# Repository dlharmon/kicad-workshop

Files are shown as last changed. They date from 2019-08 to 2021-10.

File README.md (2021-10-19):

# kicad-workshop
Material for a Kicad workshop

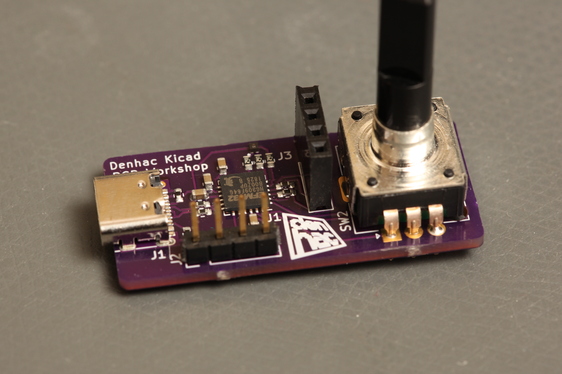
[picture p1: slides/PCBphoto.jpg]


## Overview

A three session workshop on designing and assembling PCBs with
Kicad. A small group of students will design and build a USB
widget. The instructor will provide the basic circuit and
guidance. Materials cost will be approximately $20 including PCB
fabrication, components, shipping and solder paste stencil. We will
place a shared order to reduce shipping costs.

## [Slides](https://raw.githubusercontent.com/dlharmon/kicad-workshop/master/slides/kicad-workshop.pdf)

## The device

- [Silicon Labs EFM32HG309 microcontroller](https://www.silabs.com/products/mcu/32-bit/efm32-happy-gecko), ARM Cortex M0+, 64 kiB flash, 8 kiB ram USB device interface. About $1.50.
 - Connector for [128x64 pixel OLED](https://www.aliexpress.com/item/32847040077.html?spm=a2g0s.9042311.0.0.6e644c4dlFzZIQ) Display is not included in the parts kit, order one yourself if you want it.
 - LEDs
 - rotary encoder with push switch
 - USB for power and communication, will provide Python code to communicate with it from a PC
 - This is about $3 in parts yet demonstrates quite a few things

## Prerequisites
 - Laptop with [Kicad 5.1.4](http://www.kicad.org/download/) 5.1.2 is probably OK. Last time we had a few students using 5.0.x and it was problematic.
 - [Interactive HTML BOM plugin installed](https://github.com/openscopeproject/InteractiveHtmlBom) (optional, may require installing python3-wxgtk4)
 - Electronics knowledge is not required, but helpful.
 - Programming knowledge is not required, but helpful.
 - USB C cable (C-C for newer laptops, A-C for older) by last session. I'll have a few on hand.
 - Clone or download [https://github.com/sethhillbrand/kicad_templates.git](https://github.com/sethhillbrand/kicad_templates.git)

## Firmware
 - This is entirely optional. The instructor can flash firmware for you if you are not interested.
 - [ARM Cortex compiler](https://developer.arm.com/tools-and-software/open-source-software/developer-tools/gnu-toolchain/gnu-rm/downloads) Alternately, your Linux distro may have a package `gcc-arm-none-eabi` or similar which may work.
 - [OpenOCD](http://openocd.org/) required to flash the firmware the first time and until a bootloader is developed.
 - In the fw directory, `make flash` will build and flash the firmware. It assumes an FT232H based programmer with the default USB ID.
 - usb_comm.py can be used to interact with the device from Python over USB.

### udev rules

On Linux, to avoid having to run as root (change dlharmon to your user), add the following to `/etc/udev/rules.d/99-local.rules`:

```
ATTR{idVendor}=="0403", ATTR{idProduct}=="6014", SYMLINK+="ftdi-%k", MODE="660", GROUP="dlharmon"
SUBSYSTEM=="usb", ATTR{idVendor}=="10c4", ATTR{idProduct}=="8b00", MODE="0660", GROUP="dlharmon"
```

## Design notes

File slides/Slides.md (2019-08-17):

## The PCB Download files [https://github.com/dlharmon/kicad-workshop](https://github.com/dlharmon/kicad-workshop)

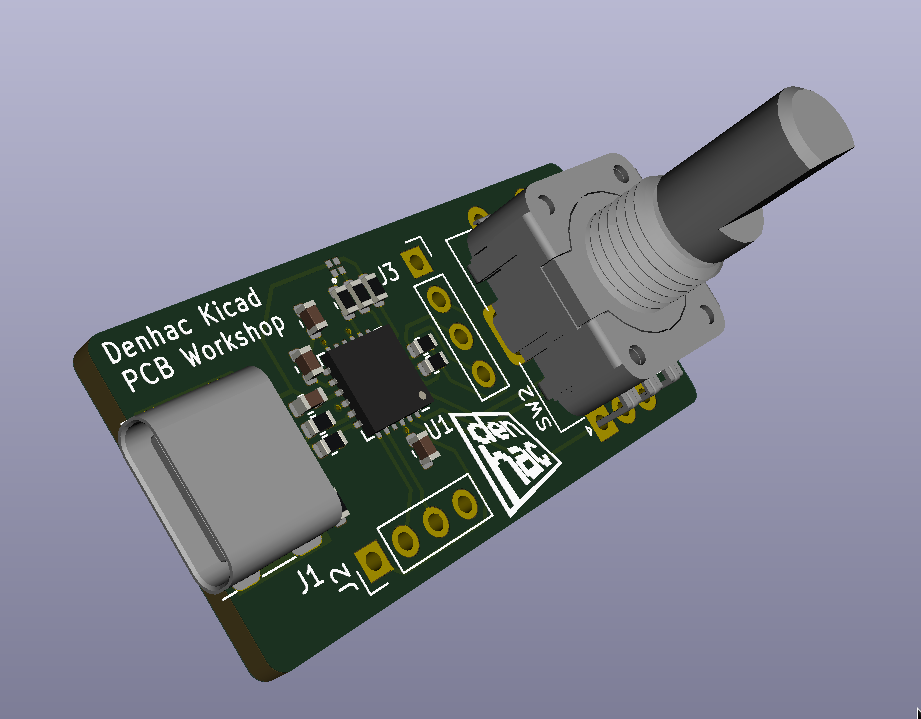
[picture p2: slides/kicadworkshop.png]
3D render


The goal was to create a inexpensive and simple PCB which demonstrates the use of Kicad, basic microcontroller interfacing and surface mount PCB assembly.

 - microcontroller with USB interface
 - Connector for OLED
 - Encoder
 - RGB LED
 - $2.97 parts cost ($1.75 microcontroller, $0.86 encoder, $0.25 USB C connector, $0.06 LED, $0.05 passives)

## PCB Material

 - FR-4: woven fiberglass with flame retardant epoxy resin
 - avoid breathing the dust
 - OSHPark uses materials with high Tg (Shengyi S1141 170, Isola FR408). These withstand the higher temperatures associated with lead free reflow soldering.
 - Other materials exist from the paper based FR-2 used in consumer electronics to exotic teflon and polyimide based materials.

## Copper layers

 - One layer - copper on one side only
 - Two layer - copper on both sides usually with plated vias connecting
 - multilayer - copper on both sides and internal copper layers

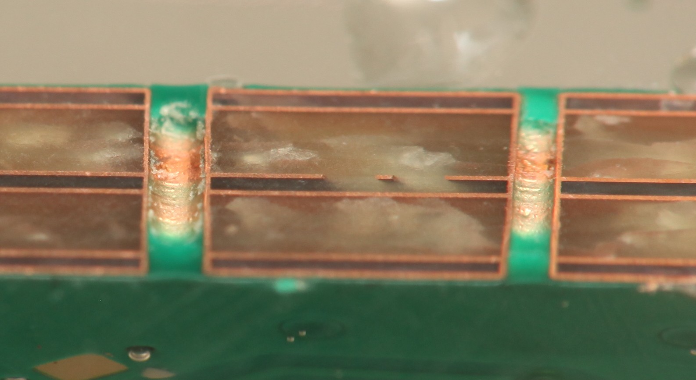
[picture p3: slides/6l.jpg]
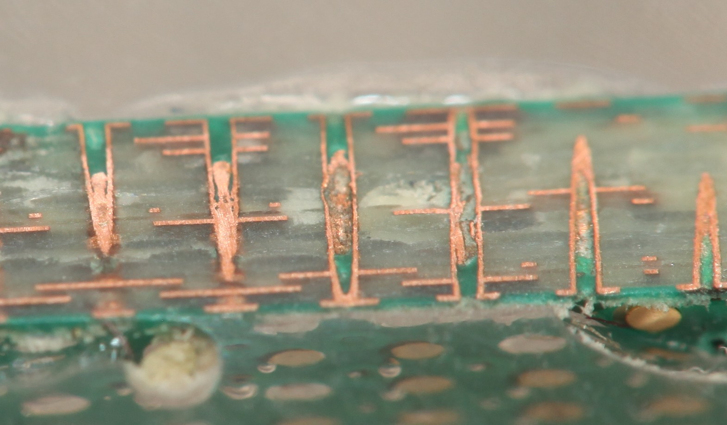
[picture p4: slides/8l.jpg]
 

## Solder mask and silk screen

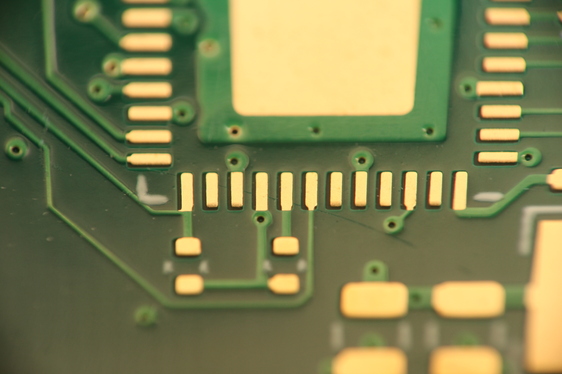
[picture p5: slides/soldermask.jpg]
solder mask and silk screen


## Surface finish

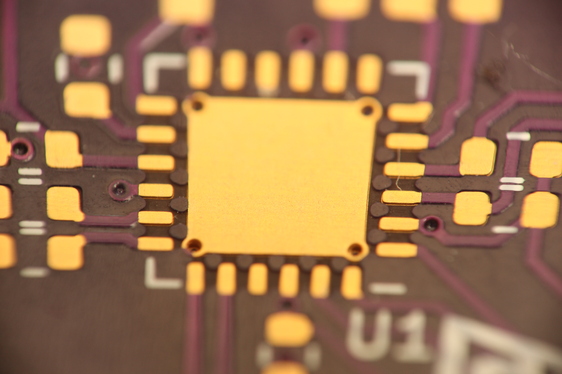
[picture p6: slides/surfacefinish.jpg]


If left bare, copper would oxidize reducing solderability.

 - ENIG (electroless nickel + immersion gold) standard with OSHPark, complex process, expensive, good for edge connectors, battery contacts, etc
 - HASL (hot air solder leveling), common, cheap. The board is dipped in molten solder and the excess is blown off with hot air. Often contains lead. Causes problems for QFN and BGA assembly. Thermally stresses boards.
 - OSP (organic solderability preservative), common in China, cheap, works well, thin waxy coating to protect bare copper from oxidation
 - immersion silver - very thin silver plating plus a tarnish inhibitor. One of my favorite finishes.
 - less common options - electrolytic gold, etc

## Solder paste

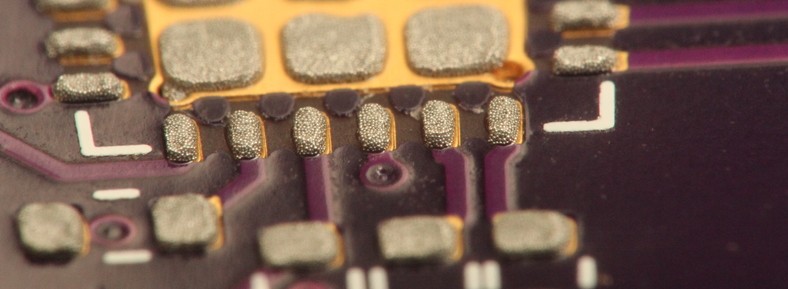
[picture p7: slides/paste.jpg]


 - Solder spheres in gel flux
 - We will use Kester NXG-1 lead free paste available from OSHStencils for $15
 - flux strips oxides from metals when hot, NXG-1 does not require cleaning of residue
 - Keep refrigerated, limited shelf life, ship overnight in summer

## Terminology

 - Trace: copper foil connecting two points on a PCB.
 - Via: a drilled hole in the PCB, plated with copper to provide an electrical connection between layers
 - Pin: terminal of a component that connects electrically to the PCB, may not be a pin on modern components, but a ball or bit of exposed metal
 - Pad: copper area on a PCB intended to be soldered to a pin
 - Net: set of electrically connected items on a PCB
 - mil = 0.001 inch = 25.4 μm
 - oz = oz / sqft = 35 μm copper

## Design rules

 - Minimum drill sizes, trace widths, spacings, annular rings
 - OSHPark: 0.152 mm trace, 0.152 mm space, 0.254 mm minimum via hole, 0.508 mm minimum via pad
 - Some manufacturers check and will reject your files if not within the rules
 - OSHPark does not check and you can cheat, but don't expect a refund if you have shorts or opens
 - [OSHPark](https://docs.oshpark.com/design-tools/kicad/kicad-design-rules/)
 - [https://github.com/sethhillbrand/kicad_templates](https://github.com/sethhillbrand/kicad_templates)
 - Preferences->Configure Paths set KICAD_TEMPLATE_DIR to location of above

## PCB Manufacturing Panels

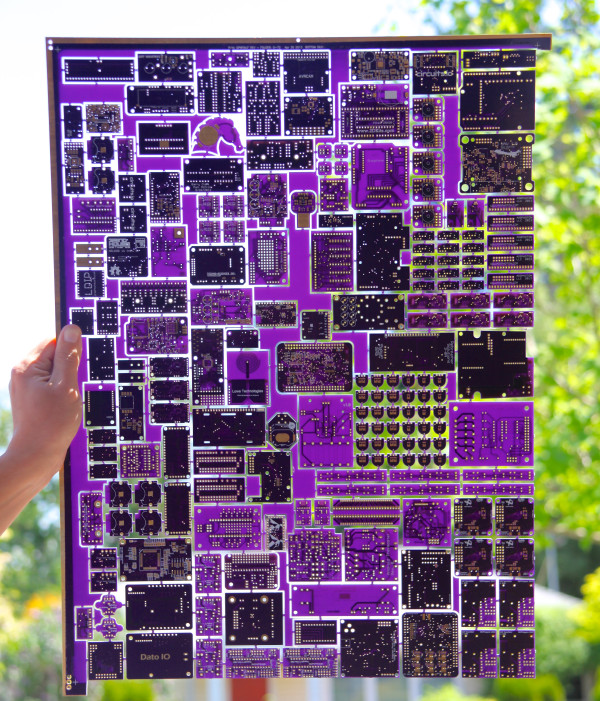
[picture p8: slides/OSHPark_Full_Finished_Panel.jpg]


PCBs are manufactured on large panels. In the US, they are typically
24x18 inches. Most PCB manufacturers will tile a single board to cover
an entire panel resulting in high minimum order cost. Shared panel
manufacturers array many designs to reduce cost and waste. Photo: OSHPark

## Where to get PCBs and stencils

This is simply a list of some places I've used.

 - [OSHPark](https://oshpark.com) - Portland, OR shared panel service. Highly recommended.
   * Purple mask, except flex has clear mask, clear mask on black FR4 option
   * $5 per square inch 2 layer, 12 days or 5 days for 2x the price
   * $10 per square inch 4 layer, 12 days
   * $10 per square inch 2 layer flex
 - [EuroCircuits](https://eurocircuits.com) - shared panel, more options than most
 - [PCBPool](https://pcb-pool.com) - Ireland, shared panel, offers 6 layer
 - [JLCPCB](https://jlcpcb.com) - China, shared panel service, low prices, good quality. Does make some edits to files submitted before printing. Offers stencils and parts too. $17 DHL shipping.
 - [WellPCB](https://wellpcb.com) - China, build to spec
 - [Circuits West](http://circuitswest.com) - Longmont, CO
 - [Advanced Circuits](https://4pcb.com) - Aurora,  CO

### Stencils
 [OSHStencils](https://oshstencils.com): fast, reasonable cost. Stainless steel or polyimide plastic.

## Where to get parts
 - [Digikey](https://digikey.com) - best search, lots of stock
 - [Mouser](https://mouser.com) - similar to Digikey, search is not quite as good, but decent
 - [Arrow](https://arrow.com), [Avnet](https://avnet.com) - traditional distributors, pricing is negotiable
 - [Adafruit](https://www.adafruit.com/), [SparkFun](https://sparkfun.com) - Hobbyist friendly, less overwhelming selection.
 - [LCSC](https://lcsc.com) - China, low prices, not an authorized distributor for some of what they sell.
 - [Aliexpress](https://aliexpress.com), [Ebay](https://ebay.com), Amazon sellers - use caution.

 - [FindChips](https://findchips.com), [Octopart](https://octopart.com): parts search sites, shows price and stock and many distributors

## Passive package size codes

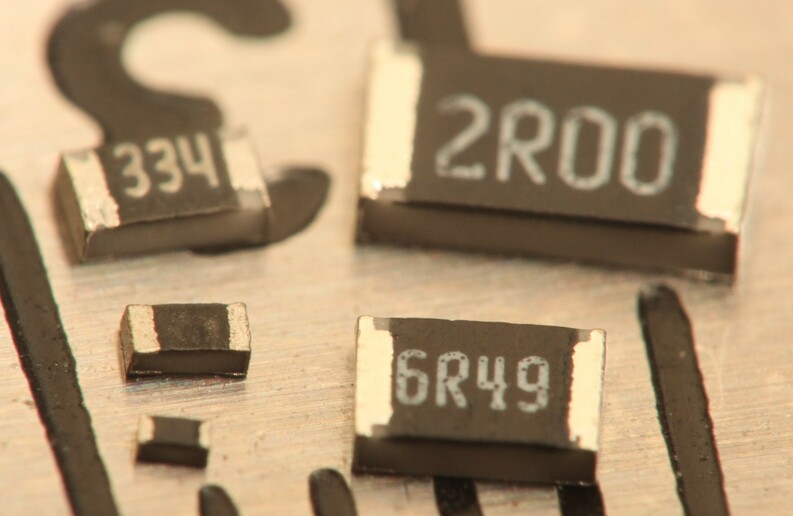
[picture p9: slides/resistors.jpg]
inch(mm) package sizes on a mm scale 0201(0603),0402(1005),0603(1608),0805(2012),1206(3216)


 - First 2 digits encode length, 2nd two width
 - The inch size codes are most prevalent including in metric countries.
 - the digits xy in the metric version encode x.y mm
 - the digits xy in the inch version encode 0.xx in

## Resistors



 - $I=\frac{V}{R}$
 - 0603 is the smallest size marked with the value - 334 indicates $33\times10^4$ ohms
 - 2R00 indicates 2.00 ohms, other markings exist including an alphanumeric code
 - Thick film is by far the most common, cheapest (0603 size is < $5 for 5000 pieces), noisy
 - Thin film is preferred for precision analog, high end audio
 - Be aware of power rating, 0603 is typically 0.1 W, $P=I^2R=\frac{V^2}{R}$

## Capacitors

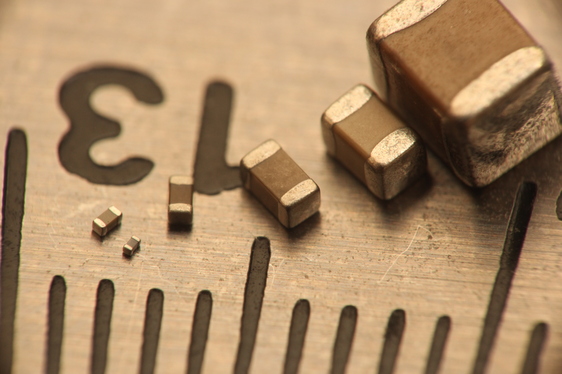
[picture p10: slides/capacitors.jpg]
multilayer ceramic capacitors in inch sizes 01005,0201,0402,0603,0805,1210


 - $I=C\frac{dv}{dt}$, no DC current flow, resists change in voltage across terminals
 - store energy
 - higher voltage and capacitance ratings require larger size
 - Many types: ceramic, film, wet aluminum electrolytic, polymer electrolytic, tantalum, etc.
 - Capacitors and their non-idealities are a highly complex topic

## Ceramic capacitors

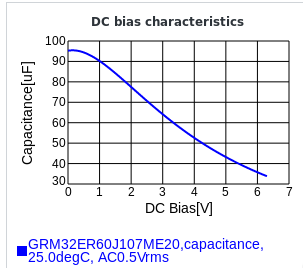
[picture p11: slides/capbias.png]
 

 - Ceramic is the most common capacitor and is highly reliable unless cracked
 - Numerous dielectrics avaliable with a wide range of properties
 - NP0/C0G are near ideal, low capacitace / volume, good for analog
 - X5R, X7R, X6S, etc have a large capacitance drop with applied voltage, some temperature variation, very common
 - Y5V, Z5U - avoid, large variation over temperature

## IC packages

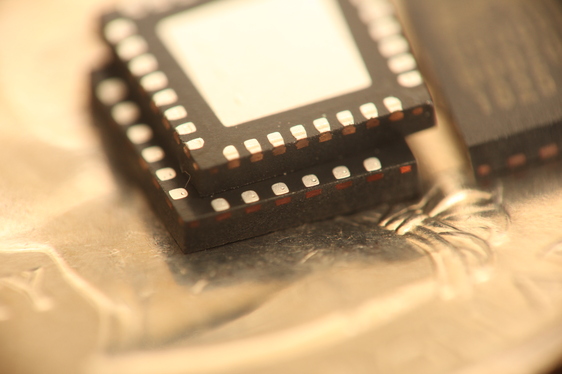
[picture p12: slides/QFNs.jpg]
QFN
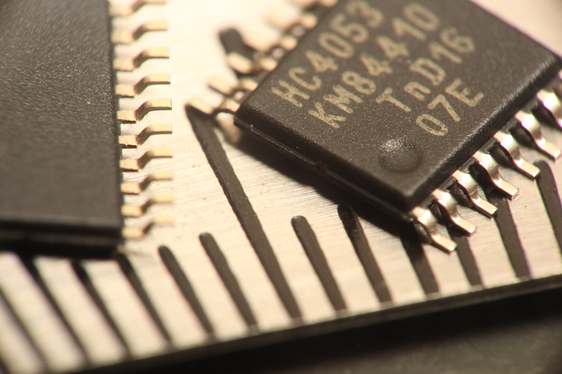
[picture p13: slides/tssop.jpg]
TSSOP
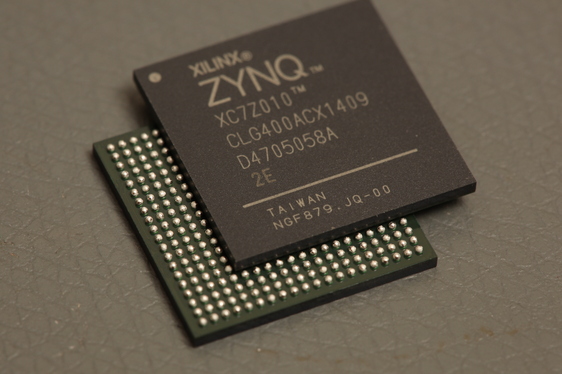
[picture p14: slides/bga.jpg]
BGA
  

 - QFN, TSSOP, BGA
 - more variety than this out there
 - BGA has an undeserved reputation for being difficult

## Moisture sensitive and ESD sensitive parts

 - Moisture senstive - part absorbs water which boils in reflow, causing cracking, these parts are shipped with dessicant in special bags
 - ESD is when a person or object builds up charge and then discharges to a circuit or component, like when walking across carpet and then touching a metal object. This can be thousands of volts and can damage electronics. Our dry climate makes this problem worse. These parts should be kept in their bags and handled using an ESD mat and/or wrist strap. Nothing in this project is particularly sensitive.

## Get started - Create empty project

 - Add project specific schematic library (Preferences->Manage Symbol Libraries)
 - Add project specific footprints library (Preferences->Manage Footprint Libraries)
 - Set up schematic page properties

## USB C Device interface

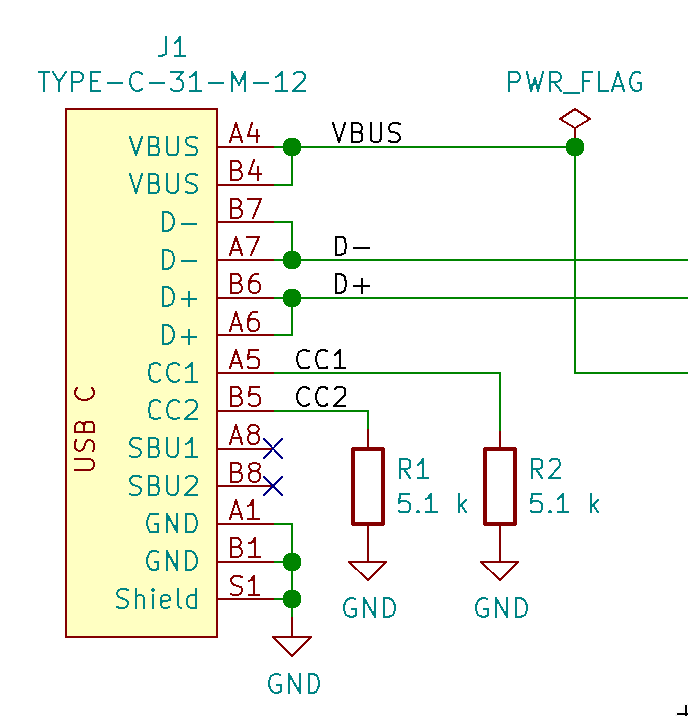
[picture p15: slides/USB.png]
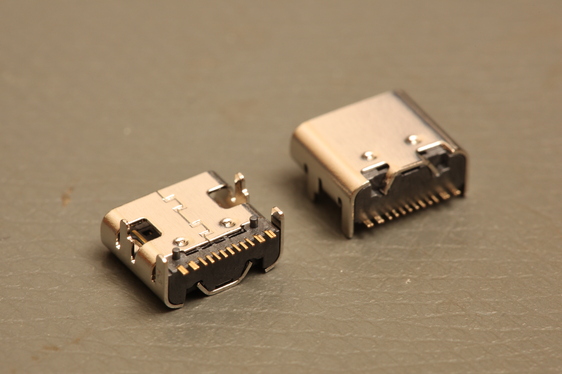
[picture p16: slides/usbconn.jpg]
 

 - Add USB C symbol - kicad-workshop:USB-C_HRO16
 - Add ground symbol
 - add wires between USB ground pins, ground symbol
 - add a 5.1 k resistor (Device:R), set footprint, connect to CC2, ground
 - duplicate for CC1

## USB C Device interface (continued)

 

 - label CC1, CC2
 - add wires to D-, D+, A6 and A7 will be connected in one cable orientation, B6, B7 in the other, so need to parallel.
 - add wires for VBUS
 - add no connects for SBU1, SBU2

## Microcontroller

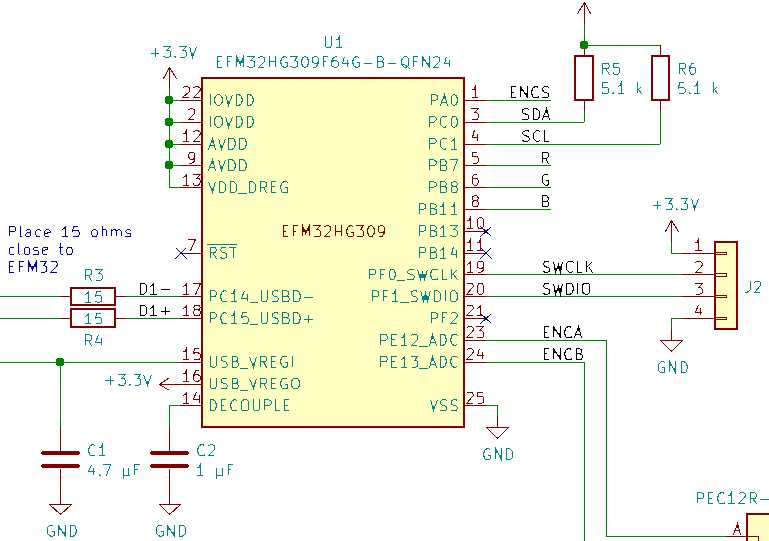
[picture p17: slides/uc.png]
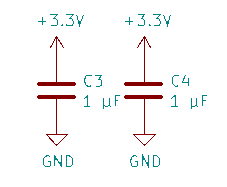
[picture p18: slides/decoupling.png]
 

- Connect ground, 3.3 V symbols
 - Capacitors - data sheet, [AN0046](https://www.silabs.com/documents/public/application-notes/AN0046.pdf)
 - The USB spec and AN0046 conflict on connector grounding, following USB spec
 - Debug connector

## LED

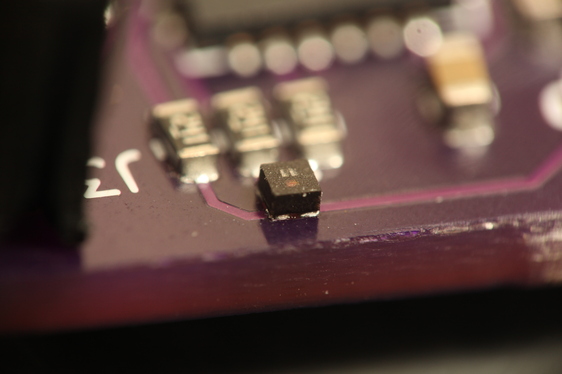
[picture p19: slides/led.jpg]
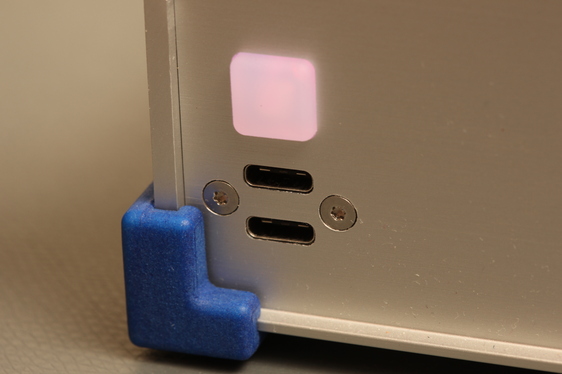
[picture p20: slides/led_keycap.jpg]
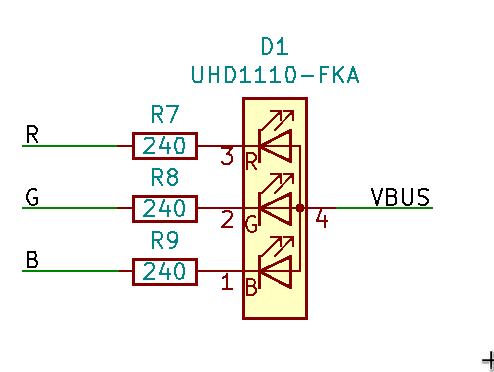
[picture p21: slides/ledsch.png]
  

 - Symbol: kicad-workshop:UHD1110-FKA, Cree UHD1110-FKA
 - Footprint: kicad-workshop:LED_cree_4_1x1 (doesn't exist!)
 - Anode to VBUS (5 V) - requires up to 3.6 V so we can't use the 3.3 V supply
 - Current limiting resistors - $R_{min}=\frac{5.0 V - 1.9 V}{10 mA}$
 - Red cathode to PB7 via 330 ohms
 - Green cathode to PB8 via 330 ohms
 - Blue cathode to PB11 via 330 ohms
 - These pins connect to a timer peripheral capable of pulse width modulation

## Encoder

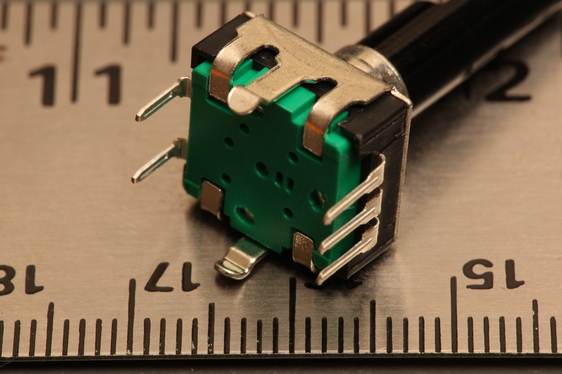
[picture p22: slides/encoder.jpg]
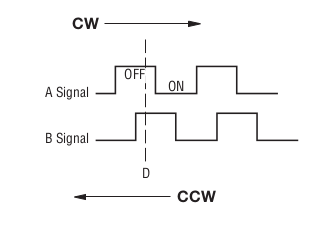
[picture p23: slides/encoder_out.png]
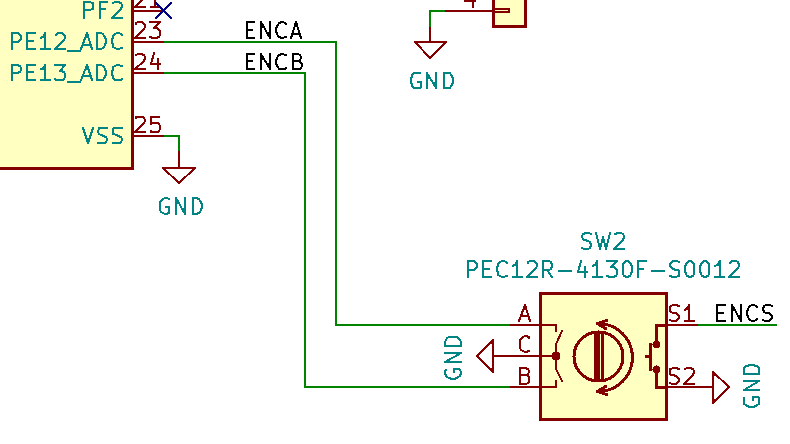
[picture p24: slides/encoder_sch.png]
  

 - Symbol: Device:Rotary_Encoder_Switch
 - Value: PEC12R-4130F-S0012
 - Footprint: Rotary_Encoder:RotaryEncoder_Alps_EC12E-Switch_Vertical_H20mm
 - Pull up resistors enabled internal to the microcontroller hold lines at logic 1
 - Switches in the encoder connect lines to ground forcing logic 0
 - A to PE12, B to PE13, S1 to PA0

## OLED header
 - Create our own symbol
 - Pin 1: GND, power in
 - Pin 2: 3.3 V, power in
 - Pin 3: SCL, bidirectional
 - Pin 4: SDA, bidirectional
 - SDA and SCL require pullup resistors, use 5.1 k
 - Interface is I2C, SDA is PC0, SCL is PC1 for the I2C0 peripheral

## Serial Wire Debug (SWD) header

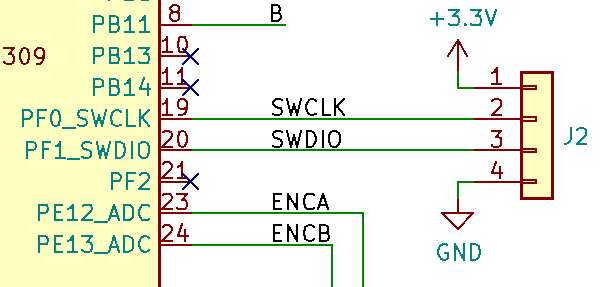
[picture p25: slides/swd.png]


 - Used to program bootloader into the microcontroller
 - Can be used to debug microcontroller code with GDB
 - Symbol: Connector_Generic:Conn_01x04
 - Footprint: Connector_PinHeader_2.54mm:PinHeader_1x04_P2.54mm_Vertical

## Misc

 - tooling holes for stencil alignment
 - power flags for ERC
 - run ERC

## PCB Layout - design rule setup
 - File->Board Setup
 - Select layer count

## Create LED footprint



## Placement

 - First place parts with mechanical location requirements
 - Place remaining components minimizing connection lengths

## Routing
 - Add a ground plane
 - Add ground vias
 - Avoid placing vias in pads - air bubbles, paste sucked down hole
 - Set thermal relief as desired on through hole parts
 - Trace width consideration
   * Thermal, resistance - use Kicad's calculator
   * Design rules
   * Mechanical robustness
   * Impedance (advanced topic)

## Board outline

 - Edge.Cuts layer
 - Segments must exactly meet
 - Rounded corners are nice for handling

## Silkscreen, decoration

 - Label connector pins if space available
 - Identification text
 - Logos, artwork if desired

## Order PCB

 - run design rule check
 - [https://oshpark.com](https://oshpark.com)
 - browse for files button
 - select your .kicad_pcb file
 - review plots
 - add to cart and pay

## Gerber, Excellon files

 - Most board manufacturers require this format (zipped)
 - File per layer plus drill files
 - File->Plot
 - Check all
 - set output folder (you get a large number of files)
 - Plot
 - Drill file
 - View with gerber viewer
 - zip and send to manufacturer

## Order stencil

 Send your .kicad_pcb file to the instructor to be arrayed with the others and ordered. If ordering on your own do the following:

 - File->Plot
 - uncheck all but F.Paste (B.Paste if double sided)
 - Plot
 - order from [https://oshstencils.com](https://oshstencils.com)

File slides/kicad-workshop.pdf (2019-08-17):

### The PCB Download files https://github.com/dlharmon/kicad-workshop


The goal was to create a inexpensive and simple PCB which demonstrates the use of Kicad, basic microcontroller interfacing and surface mount PCB assembly.

microcontroller with USB interface
Connector for OLED
Encoder
RGB LED
$2.97 parts cost ($1.75 microcontroller, $0.86 encoder, $0.25 USB C connector, $0.06 LED, $0.05 passives)

### PCB Material

FR-4: woven fiberglass with flame retardant epoxy resin
avoid breathing the dust
OSHPark uses materials with high Tg (Shengyi S1141 170, Isola FR408). These withstand the higher temperatures associated with lead free reflow soldering.
Other materials exist from the paper based FR-2 used in consumer electronics to exotic teflon and polyimide based materials.

### Copper layers

One layer - copper on one side only
Two layer - copper on both sides usually with plated vias connecting multilayer - copper on both sides and internal copper layers


### Solder mask and silk screen


### Surface finish


If left bare, copper would oxidize reducing solderability.

ENIG (electroless nickel + immersion gold) standard with OSHPark, complex process, expensive, good for edge connectors, battery contacts, etc
HASL (hot air solder leveling), common, cheap. The board is dipped in molten solder and the excess is blown off with hot air. Often contains lead. Causes problems for QFN and BGA assembly. Thermally stresses boards.
OSP (organic solderability preservative), common in China, cheap, works well, thin waxy coating to protect bare copper from oxidation
immersion silver - very thin silver plating plus a tarnish inhibitor. One of my favorite finishes. less common options - electrolytic gold, etc

### Solder paste


Solder spheres in gel flux
We will use Kester NXG-1 lead free paste available from OSHStencils for $15
flux strips oxides from metals when hot, NXG-1 does not require cleaning of residue Keep refrigerated, limited shelf life, ship overnight in summer

### Terminology

Trace: copper foil connecting two points on a PCB.
Via: a drilled hole in the PCB, plated with copper to provide an electrical connection between layers
Pin: terminal of a component that connects electrically to the PCB, may not be a pin on modern components, but a ball or bit of exposed metal
Pad: copper area on a PCB intended to be soldered to a pin
Net: set of electrically connected items on a PCB
mil = 0.001 inch = 25.4 μm
oz = oz / sqft = 35 μm copper

### Design rules

Minimum drill sizes, trace widths, spacings, annular rings
OSHPark: 0.152 mm trace, 0.152 mm space, 0.254 mm minimum via hole, 0.508 mm minimum via pad
Some manufacturers check and will reject your files if not within the rules
OSHPark does not check and you can cheat, but don’t expect a refund if you have shorts or opens
OSHPark (https://docs.oshpark.com/design-tools/kicad/kicad-design-rules/)
https://github.com/sethhillbrand/kicad_templates
Preferences->Configure Paths set KICAD_TEMPLATE_DIR to location of above

### PCB Manufacturing Panels


PCBs are manufactured on large panels. In the US, they are typically 24x18 inches. Most PCB manufacturers will tile a single board to cover an entire panel resulting in high minimum order cost. Shared panel manufacturers array many designs to reduce cost and waste. Photo: OSHPark

### Where to get PCBs and stencils

This is simply a list of some places I’ve used.

OSHPark (https://oshpark.com) - Portland, OR shared panel service. Highly recommended. Purple mask, except flex has clear mask, clear mask on black FR4 option $5 per square inch 2 layer, 12 days or 5 days for 2x the price
$10 per square inch 4 layer, 12 days
$10 per square inch 2 layer flex
EuroCircuits (https://eurocircuits.com) - shared panel, more options than most
PCBPool (https://pcb-pool.com) - Ireland, shared panel, offers 6 layer
JLCPCB (https://jlcpcb.com) - China, shared panel service, low prices, good quality. Does make some edits to files submitted before printing. Offers stencils and parts too. $17 DHL shipping.
WellPCB (https://wellpcb.com) - China, build to spec
Circuits West (http://circuitswest.com) - Longmont, CO
Advanced Circuits (https://4pcb.com) - Aurora, CO

Stencils
OSHStencils: (https://oshstencils.com) fast, reasonable cost. Stainless steel or polyimide plastic.

### Where to get parts

Digikey (https://digikey.com) - best search, lots of stock

Mouser (https://mouser.com) - similar to Digikey, search is not quite as good, but decent

Arrow, (https://arrow.com) Avnet (https://avnet.com) - traditional distributors, pricing is negotiable

Adafruit, (https://www.adafruit.com/) SparkFun (https://sparkfun.com) - Hobbyist friendly, less overwhelming selection.

LCSC (https://lcsc.com) - China, low prices, not an authorized distributor for some of what they sell.

Aliexpress, (https://aliexpress.com) Ebay, (https://ebay.com) Amazon sellers - use caution.

FindChips, (https://findchips.com) Octopart: (https://octopart.com) parts search sites, shows price and stock and many distributors

### Passive package size codes


Figure 2: inch(mm) package sizes on a mm scale 0201(0603),0402(1005),0603(1608),0805(2012),1206(3216)

First 2 digits encode length, 2nd two width
The inch size codes are most prevalent including in metric countries.
the digits xy in the metric version encode x.y mm
the digits xy in the inch version encode 0.xx in

### Resistors

I = V
R
0603 is the smallest size marked with the value - 334 indicates 33 × 10⁴
ohms
2R00 indicates 2.00 ohms, other markings exist including an alphanumeric code
Thick film is by far the most common, cheapest (0603 size is < $5 for 5000 pieces), noisy Thin film is preferred for precision analog, high end audio
Be aware of power rating, 0603 is typically 0.1 W, P = I²R = V

2
R

### Capacitors


Figure 3: multilayer ceramic capacitors in inch sizes 01005,0201,0402,0603,0805,1210

### I = C dv

dt , no DC current flow, resists change in voltage across terminals
store energy
higher voltage and capacitance ratings require larger size
Many types: ceramic, film, wet aluminum electrolytic, polymer electrolytic, tantalum, etc. Capacitors and their non-idealities are a highly complex topic

### Ceramic capacitors


Ceramic is the most common capacitor and is highly reliable unless cracked
Numerous dielectrics avaliable with a wide range of properties
NP0/C0G are near ideal, low capacitace / volume, good for analog
X5R, X7R, X6S, etc have a large capacitance drop with applied voltage, some temperature variation, very common
Y5V, Z5U - avoid, large variation over temperature

### IC packages


QFN, TSSOP, BGA
more variety than this out there
BGA has an undeserved reputation for being difficult

### Moisture sensitive and ESD sensitive parts

Moisture senstive - part absorbs water which boils in reflow, causing cracking, these parts are shipped with dessicant in special bags
ESD is when a person or object builds up charge and then discharges to a circuit or component, like when walking across carpet and then touching a metal object. This can be thousands of volts and can damage electronics. Our dry climate makes this problem worse. These parts should be kept in their bags and handled using an ESD mat and/or wrist strap. Nothing in this project is particularly sensitive.

### Get started - Create empty project

Add project specific schematic library (Preferences->Manage Symbol Libraries) Add project specific footprints library (Preferences->Manage Footprint Libraries) Set up schematic page properties

### USB C Device interface


Add USB C symbol - kicad-workshop:USB-C_HRO16
Add ground symbol
add wires between USB ground pins, ground symbol
add a 5.1 k resistor (Device:R), set footprint, connect to CC2, ground duplicate for CC1

### USB C Device interface (continued)


label CC1, CC2
add wires to D-, D+, A6 and A7 will be connected in one cable orientation, B6, B7 in the other, so need to parallel.
add wires for VBUS
add no connects for SBU1, SBU2

### Microcontroller


Connect ground, 3.3 V symbols
Capacitors - data sheet, AN0046 (https://www.silabs.com/documents/public/application-notes/AN0046.pdf)
The USB spec and AN0046 conflict on connector grounding, following USB spec Debug connector

### LED


Symbol: kicad-workshop:UHD1110-FKA, Cree UHD1110-FKA
Footprint: kicad-workshop:LED_cree_4_1x1 (doesn’t exist!)
Anode to VBUS (5 V) - requires up to 3.6 V so we can’t use the 3.3 V supply Current limiting resistors - Rmin =

5.0V −1.9V
10mA
Red cathode to PB7 via 330 ohms
Green cathode to PB8 via 330 ohms
Blue cathode to PB11 via 330 ohms
These pins connect to a timer peripheral capable of pulse width modulation

### Encoder


Symbol: Device:Rotary_Encoder_Switch
Value: PEC12R-4130F-S0012
Footprint: Rotary_Encoder:RotaryEncoder_Alps_EC12E-Switch_Vertical_H20mm Pull up resistors enabled internal to the microcontroller hold lines at logic 1 Switches in the encoder connect lines to ground forcing logic 0
A to PE12, B to PE13, S1 to PA0

### OLED header

Create our own symbol
Pin 1: GND, power in
Pin 2: 3.3 V, power in
Pin 3: SCL, bidirectional
Pin 4: SDA, bidirectional
SDA and SCL require pullup resistors, use 5.1 k
Interface is I2C, SDA is PC0, SCL is PC1 for the I2C0 peripheral

### Serial Wire Debug (SWD) header


Used to program bootloader into the microcontroller
Can be used to debug microcontroller code with GDB
Symbol: Connector_Generic:Conn_01x04
Footprint: Connector_PinHeader_2.54mm:PinHeader_1x04_P2.54mm_Vertical

### Misc

tooling holes for stencil alignment power flags for ERC
run ERC

### PCB Layout - design rule setup

File->Board Setup
Select layer count

### Create LED footprint


### Placement

First place parts with mechanical location requirements Place remaining components minimizing connection lengths

### Routing

Add a ground plane
Add ground vias
Avoid placing vias in pads - air bubbles, paste sucked down hole Set thermal relief as desired on through hole parts
Trace width consideration
Thermal, resistance - use Kicad’s calculator Design rules
Mechanical robustness
Impedance (advanced topic)

### Board outline

Edge.Cuts layer
Segments must exactly meet Rounded corners are nice for handling

### Silkscreen, decoration

Label connector pins if space available Identification text
Logos, artwork if desired

### Order PCB

run design rule check
https://oshpark.com
browse for files button
select your .kicad_pcb file review plots
add to cart and pay

### Gerber, Excellon files

Most board manufacturers require this format (zipped) File per layer plus drill files
File->Plot
Check all
set output folder (you get a large number of files) Plot
Drill file
View with gerber viewer
zip and send to manufacturer

### Order stencil

Send your .kicad_pcb file to the instructor to be arrayed with the others and ordered. If ordering on your own do the following:

File->Plot
uncheck all but F.Paste (B.Paste if double sided) Plot
order from https://oshstencils.com

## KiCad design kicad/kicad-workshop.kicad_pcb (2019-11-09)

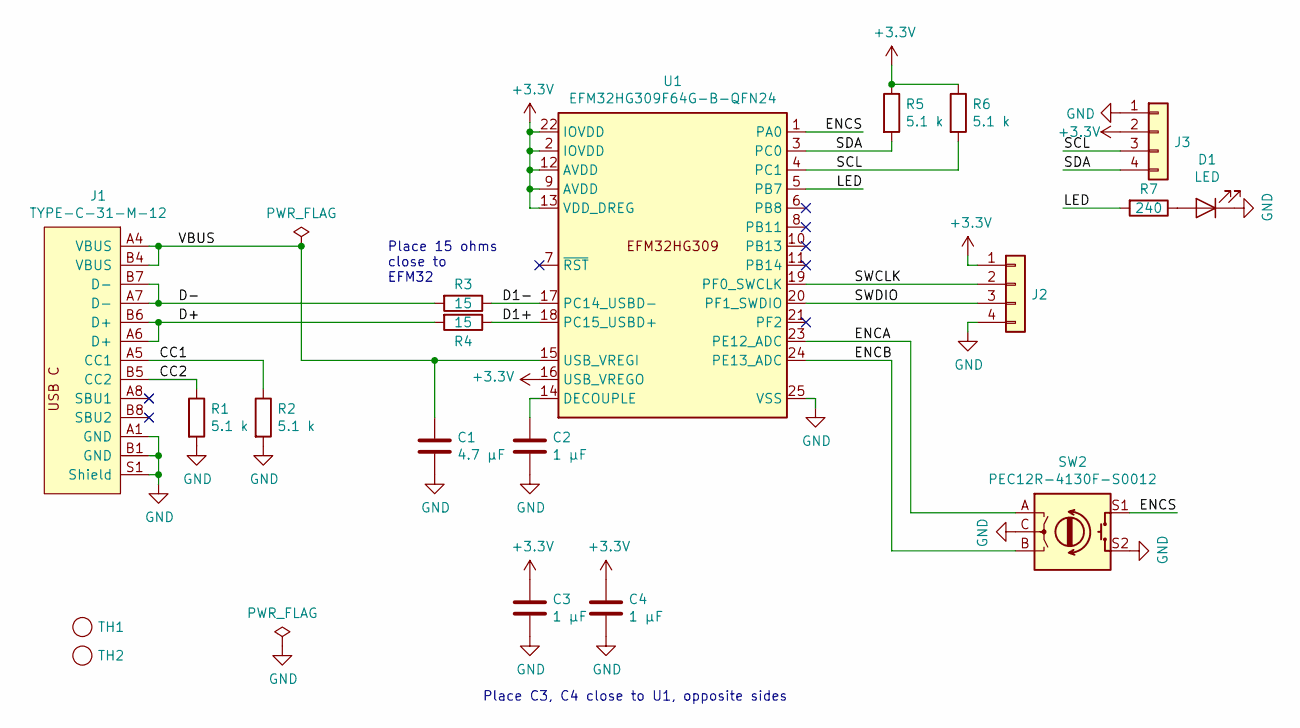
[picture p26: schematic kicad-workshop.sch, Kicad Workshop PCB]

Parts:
C1: 4.7 μF; C_0603_1608Metric
C2, C3, C4: 1 μF; C_0603_1608Metric
D1: LED; LED_0603_1608Metric
J1: TYPE-C-31-M-12; USB_C_Receptacle_HRO_TYPE-C-31-M-12
J2: Conn_01x04; PinHeader_1x04_P2.54mm_Vertical
J3: Conn_01x04; PinSocket_1x04_P2.54mm_Vertical
R1, R2, R5, R6: 5.1 k; R_0603_1608Metric
R3, R4: 15; R_0603_1608Metric
R7: 240; R_0603_1608Metric
SW2: PEC12R-4130F-S0012; RotaryEncoder_Alps_EC12E-Switch_Vertical_H20mm
TH1, TH2: tooling_hole; tooling_hole_2.55
U1: EFM32HG309F64G-B-QFN24; QFN-24-1EP_5x5mm_P0.65mm_EP3.6x3.6mm

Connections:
+3V3: C3.1, C4.1, J2.1, J3.2, R5.1, R6.1, U1.2 (IOVDD), U1.9 (AVDD), U1.12 (AVDD), U1.13 (VDD_DREG), U1.16 (USB_VREGO), U1.22 (IOVDD)
/CC1: J1.A5 (CC1), R2.1
/CC2: J1.B5 (CC2), R1.1
/D1+: R4.1, U1.18 (PC15_USBD+)
/D1-: R3.1, U1.17 (PC14_USBD-)
/D+: J1.A6 (D+), J1.B6 (D+), R4.2
/D-: J1.A7 (D-), J1.B7 (D-), R3.2
/ENCA: SW2.A, U1.23 (PE12_ADC)
/ENCB: SW2.B, U1.24 (PE13_ADC)
/ENCS: SW2.S1, U1.1 (PA0)
/LED: R7.2, U1.5 (PB7)
/SCL: J3.3, R6.2, U1.4 (PC1)
/SDA: J3.4, R5.2, U1.3 (PC0)
/SWCLK: J2.2, U1.19 (PF0_SWCLK)
/SWDIO: J2.3, U1.20 (PF1_SWDIO)
/VBUS: C1.1, J1.A4 (VBUS), J1.B4 (VBUS), U1.15 (USB_VREGI)
GND: C1.2, C2.2, C3.2, C4.2, D1.1 (K), J1.A1 (GND), J1.B1 (GND), J1.S1 (Shield), J2.4, J3.1, R1.2, R2.2, SW2.C, SW2.S2, U1.25 (VSS)
unnamed: C2.1, U1.14 (DECOUPLE)
unnamed: D1.2 (A), R7.1

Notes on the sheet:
Place 15 ohms close to EFM32
Place C3, C4 close to U1, opposite sides

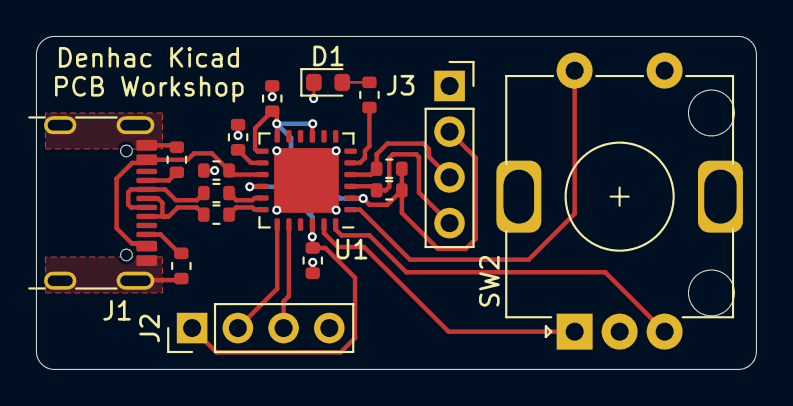
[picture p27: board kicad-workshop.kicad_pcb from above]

Board: 2 copper layers, 40.0 x 18.5 mm, 19 parts (0 on the bottom side), 19 nets.

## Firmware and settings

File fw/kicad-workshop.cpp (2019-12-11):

#include <algorithm>
#include <libopencm3/cm3/common.h>
#include <libopencm3/cm3/systick.h>
#include <libopencm3/cm3/vector.h>
#include <libopencm3/efm32/cmu.h>
#include <libopencm3/efm32/common/adc_common.h>
#include <libopencm3/efm32/common/i2c_common.h>
#include <libopencm3/efm32/gpio.h>
#include <libopencm3/efm32/hg/nvic.h>
#include <libopencm3/efm32/memorymap.h>
#include <libopencm3/efm32/timer.h>
#include <libopencm3/efm32/usb.h>
#include <libopencm3/usb/usbd.h>
#include <stdlib.h>
#include "font.h"

// R: PB7 TIM1 CC0
// G: PB8 TIM1 CC1
// B: PB11 TIM1 CC2

// ENCS: PA0 - pullup, act low
// ENCA: PE12 TIM2_CC2
// ENCB: PE13 TIM2_CC3
// SDA: PC0
// SCL: PC1
// USB: PC14, 15

#define SCL_PORT GPIOC // I2C0 AF4
#define SDA_PORT GPIOC
#define SCL_PIN GPIO1
#define SDA_PIN GPIO0

#define INT_PORT GPIOA
#define INT_PIN GPIO0

#define I2C_READ 0x01

#define TIMER_US 24
#define TIMER_MS 24000

class Timer {
private:
        uint32_t begin;
        uint32_t etime;

public:
        Timer() { reset(); }
        void reset() {
                begin = STK_CVR;
                etime = 0;
        }
        uint32_t elapsed() {
                __sync_synchronize();
                uint32_t old_etime = etime;
                etime = (etime & 0xFF000000) | (0x00FFFFFF & (begin - STK_CVR));
                if (etime < old_etime)
                        etime += 0x1000000;
                return etime;
        }
};

void delay(uint32_t cycles) {
        Timer t;
        while (t.elapsed() < cycles)
                ;
}

#define I2C_ADDR_OLED 0x78

static int i2c_transaction(uint8_t addr, const uint8_t *wdata, size_t wcount,
                           uint8_t *rdata, uint32_t rcount) {
        Timer t{};
        uint32_t timeout = 100 * TIMER_MS;
        // wait for the peripheral to be idle
        while ((I2C0_STATE & 0xE0) != 0) {
                if (t.elapsed() > timeout)
                        goto fail;
        }
        I2C0_CMD = I2C_CMD_CLEARTX | I2C_CMD_CLEARPC;
        I2C0_CMD = I2C_CMD_START;
        // I2C address
        while ((I2C0_STATUS & I2C_STATUS_TXBL) == 0) {
                if (t.elapsed() > timeout)
                        goto fail;
        }
        I2C0_TXDATA = I2C_ADDR_OLED;
        // register address
        while ((I2C0_STATUS & I2C_STATUS_TXBL) == 0) {
                if (t.elapsed() > timeout)
                        goto fail;
        }
        I2C0_TXDATA = addr;
        // data
        for (size_t i = 0; i < wcount; i++) {
                while ((I2C0_STATUS & I2C_STATUS_TXBL) == 0) {
                        if (t.elapsed() > timeout)
                                goto fail;
                }
                I2C0_TXDATA = wdata[i];
        }
        // wait for transmission to complete
        while ((I2C0_STATUS & I2C_STATUS_TXC) == 0) {
                if (t.elapsed() > timeout)
                        goto fail;
        }
        if (rcount != 0) {
                I2C0_CMD = I2C_CMD_CLEARTX | I2C_CMD_CLEARPC;
                I2C0_CMD = I2C_CMD_START;
                while ((I2C0_STATUS & I2C_STATUS_TXBL) == 0) {
                        if (t.elapsed() > timeout)
                                goto fail;
                }
                I2C0_TXDATA = I2C_ADDR_OLED | I2C_READ;
        }
        for (size_t i = 0; i < rcount; i++) {
                while ((I2C0_STATUS & I2C_STATUS_RXDATAV) == 0) {
                        if (t.elapsed() > timeout)
                                goto fail;
                }
                rdata[i] = I2C0_RXDATA;
                if ((i + 1) == rcount)
                        I2C0_CMD = I2C_CMD_NACK;
                else
                        I2C0_CMD = I2C_CMD_ACK;
        }
        I2C0_CMD = I2C_CMD_STOP;
        return 0;
fail:
        I2C0_CMD = I2C_CMD_ABORT;
        return -1;
}

static void i2c_write(uint8_t addr, uint8_t data) {
        i2c_transaction(addr, &data, 1, NULL, 0);
}

static void i2c_write(uint8_t addr, const void *data, int count) {
        i2c_transaction(addr, (uint8_t *)data, count, NULL, 0);
}

static uint32_t read_adc(uint32_t input, uint32_t ref) {
        ADC0_SINGLECTRL =
            (5 << 20) | ((ref & 0x7) << 16) | ((input & 0xF) << 8);
        ADC0_CMD = ADC_CMD_SINGLESTART;
        while ((ADC0_STATUS & ADC_STATUS_SINGLEDV) == 0)
                ;
        return ADC0_SINGLEDATA;
}

static uint32_t correct_temp(uint32_t temp) {
        int cal_v = DI_ADC0_TEMP_0_READ_1V25 >> 4;
        int tc = temp - cal_v;
        // 1/6.3 deg C per ADC code, multiply by
        // 10*65536
        tc *= 104025;
        tc >>= 16;
        tc = DI_CAL_TEMP_0 * 10 - tc;
        // tc is now 10 * temp in deg C
        return tc;
}

static void out_cb(usbd_device *usbd_dev, uint8_t ep) {
        uint32_t buf[16] __attribute__((aligned(4)));
        uint16_t len = usbd_ep_read_packet(usbd_dev, ep, (uint8_t *)buf, 64);
        if (len < 8)
                return;
        if (buf[0] == 0) {
                uint32_t rv[4];
                rv[0] = DI_UNIQUE_0;
                rv[1] = DI_UNIQUE_1;
                rv[2] = DI_MEM_INFO_FLASH | (DI_MEM_INFO_RAM << 16);
                rv[3] = DI_PART_NUMBER | (DI_PART_FAMILY << 16) |
                        (DI_PROD_REV << 24);
                usbd_ep_write_packet(usbd_dev, 0x82, &rv[0], sizeof(rv));
                return;
        }
        if (buf[0] == 3) {
                uint32_t rv = read_adc(buf[1], buf[2]);
                if (buf[1] == 8) {
                        // it's the temp sensor, convert to deg C
                        rv = correct_temp(rv);
                }
                usbd_ep_write_packet(usbd_dev, 0x82, &rv, 4);
                return;
        }
        if (buf[0] == 4) {
                TIMER1_CC0_CCV = buf[1] & 0xFFFF;
                TIMER1_CC1_CCV = buf[1] >> 16;
                TIMER1_CC2_CCV = buf[2] & 0xFFFF;
                return;
        }
        if (buf[0] == 5) {
                uint32_t rv = 0xDEADBEEF;
                usbd_ep_write_packet(usbd_dev, 0x82, &rv, 4);
                return;
        }
        return;
}

static char serial_string[17] = "serial";
static const char manufacturer_string[] = "Denhac";
static const char product_string[] = "Kicad workshop";

static const char *usb_strings[] = {
    manufacturer_string,
    product_string,
    serial_string,
};

extern "C" const struct usb_device_descriptor usb_dev_descr;
extern "C" const struct usb_endpoint_descriptor endp_bulk[2];
extern "C" const struct usb_interface_descriptor usb_interface_desc[1];
extern "C" const struct usb_interface usb_interfaces[1];
extern "C" const struct usb_config_descriptor usb_config_descr;

static uint8_t usbd_control_buffer[128];

static void usb_set_config(usbd_device *usbd_dev, uint16_t wValue) {
        (void)wValue;
        usbd_ep_setup(usbd_dev, 0x01, USB_ENDPOINT_ATTR_BULK, 64, out_cb);
        usbd_ep_setup(usbd_dev, 0x82, USB_ENDPOINT_ATTR_BULK, 64, NULL);
}

static usbd_device *usbd_dev;

void usb_isr(void) { usbd_poll(usbd_dev); }

static void hex_str(uint32_t x, char *s) {
        for (int i = 0; i < 8; i++) {
                uint32_t hexit = x >> 28;
                if (hexit < 10)
                        s[i] = '0' + hexit;
                else
                        s[i] = 'A' + (hexit - 10);
                x <<= 4;
        }
}

#include <stdio.h>

static void temperature_str(uint32_t x, char *s) {
        s[7] = 0;
        s[6] = 'C';
        s[5] = ' ';
        s[4] = '0' + (x % 10);
        s[3] = '.';
        for (int i = 2; i >= 0; i--) {
                x /= 10;
                s[i] = '0' + (x % 10);
        }
}

int isr_count = 0;

void gpio_even_isr(void) { GPIO_IFC = 0xFFFF; }

class Encoder {
private:
        uint32_t angle = 0;
        int last_change = 0;
        int pins_prev = 3;
        uint32_t get_pins() { return 0x3 & (GPIO_PE_DIN >> 12); }

public:
        bool pushed_raw() { return !(0x1 & (GPIO_PA_DIN >> 0)); }
        void update() {
                int p = get_pins();
                if (p == pins_prev)
                        return;
                // 0 rose
                if ((p & 1) && (!(pins_prev & 1)))
                        angle += (p & 2) ? -1 : 1;
                // 0 fell
                else if ((!(p & 1)) && (pins_prev & 1))
                        angle += (p & 2) ? 1 : -1;
                pins_prev = p;
        }
        uint32_t get_angle() { return angle; }
} encoder;

// this interrupt fires every 2.730666 ms (65536 / 24 MHz)
void timer1_isr(void) {
        TIMER1_IFC = 1; // clear the interrupt
        encoder.update();
        isr_count++;
}

// each byte is a column of 8 pixels
uint8_t fb[1024];

static void OLED_text(const char *const text, int startpos,
                      uint8_t inverse = 0) {
        for (size_t i = 0; text[i] != 0; i++) {
                if (startpos + 6 * i + 6 >= sizeof(fb))
                        break;
                for (int j = 0; j < 5; j++) {
                        fb[startpos + (6 * i) + j] =
                            inverse ^ font[text[i] * 5 + j];
                }
                fb[startpos + (6 * i) + 5] = inverse;
        }
}

// update the OLED display with the frame buffer
static void OLED_update() {
        for (int i = 0; i < 8; i++) {
                i2c_write(0, 0xB0 + i); // set page
                i2c_write(0, 0x02);     // set lower column address
                i2c_write(0, 0x10);     // set higher column address
                // write page
                i2c_transaction(0x40, &fb[128 * i], 128, NULL, 0);
        }
}

static void OLED_init() {
        // loosely based on
        // https://github.com/bitbank2/oled_96/blob/master/oled96.c

        constexpr uint8_t oled64_init[] = {
            0xae,       // display off
            0xd5,       // set display clock div
            0x80,       // clock div value
            0xa8,       // set multiplex
            0x3f,       // multiplex value
            0xd3,       // set display offset
            0x00,       // display offset
            0x40,       // set start line to 0
            0x8d,       // set charge pump
            0x14,       // charge pump internal VCC?
            0xa1,       // segment remap
            0xc8,       // scan direction
            0xda,       // set com pins HW config
            0x12,       // arg for above ?
            0x81,       // set contrast Bank 0
            0xcf,       // arg for above ?
            0xd9,       // set precharge
            0xf1,       // precharge arg?
            0xdb,       // VCOMH deslect level
            0x40,       // VCOMH arg?
            0xa4,       // not forced to all on
            0xa6,       // not inverse
            0x20, 0x00, // memory addressing mode
            0xaf        // display on
        };

        i2c_write(0, oled64_init, sizeof(oled64_init));

        OLED_text(serial_string, 0);
        OLED_text("Denhac Kicad Workshop", 256);
        OLED_text("Temp = ", 384);
}

int main(void) {
        // use the 24 MHz USB clock as our main clock
        CMU_CMD = CMU_CMD_USBCCLKSEL_USHFRCO | (5 << 0);

        CMU_HFPERCLKEN0 = CMU_HFPERCLKEN0_I2C0 | CMU_HFPERCLKEN0_GPIO |
                          CMU_HFPERCLKEN0_ADC0 | CMU_HFPERCLKEN0_TIMER1 |
                          CMU_HFPERCLKEN0_TIMER2;

        // configure GPIOs

        // RGB LED
        // R: PB7 TIM1 CC0
        // G: PB8 TIM1 CC1
        // B: PB11 TIM1 CC2
        gpio_mode_setup(GPIOB, GPIO_MODE_PUSH_PULL, GPIO7 | GPIO8 | GPIO11);

        // ENCA: PE12 TIM2_CC2
        // ENCB: PE13 TIM2_CC3
        // ENCS: PA0 - pullup, act low
        gpio_mode_setup(GPIOE, GPIO_MODE_INPUT_PULL_FILTER, GPIO12 | GPIO13);
        GPIO_P_DOUTSET(GPIOE) = GPIO12 | GPIO13;
        gpio_mode_setup(INT_PORT, GPIO_MODE_INPUT_PULL_FILTER, INT_PIN);
        GPIO_P_DOUTSET(INT_PORT) = INT_PIN;

        TIMER1_CTRL = (1 << 6); // run in debug
        TIMER1_ROUTE = (3 << 16) | 7;
        TIMER1_TOP = 0xFFFF;
        // set all 3 outputs to inverted PWM
        TIMER1_CC0_CTRL = TIMER_CC_CTRL_MODE_PWM | TIMER_CC_CTRL_OUTINV;
        TIMER1_CC1_CTRL = TIMER_CC_CTRL_MODE_PWM | TIMER_CC_CTRL_OUTINV;
        TIMER1_CC2_CTRL = TIMER_CC_CTRL_MODE_PWM | TIMER_CC_CTRL_OUTINV;
        TIMER1_CC0_CCV = 0x50;
        TIMER1_CC1_CCV = 0x0;
        TIMER1_CC2_CCV = 0x50;
        TIMER1_IEN = 1; // overflow interrupt enabled

        TIMER1_CMD = 1;

        GPIO_EXTIPSELL = 0;       // PA0 as ext interrupt
        GPIO_EXTIFALL = (1 << 0); // falling
        GPIO_EXTIRISE = (1 << 0); // rising
        GPIO_IEN = (1 << 0);

        // I2C0
        GPIO_P_DOUTSET(SCL_PORT) = SCL_PIN;
        gpio_mode_setup(SCL_PORT, GPIO_MODE_WIRED_AND, SCL_PIN);
        gpio_mode_setup(SDA_PORT, GPIO_MODE_WIRED_AND, SDA_PIN);
        I2C0_CTRL = I2C_CTRL_CLTO(I2C_CTRL_CLTO_1024PPC) | I2C_CTRL_GIBITO |
                    I2C_CTRL_BTO(I2C_CTRL_BTO_160PCC) | I2C_CTRL_CLHR_STANDARD |
                    I2C_CTRL_EN;
        I2C0_ROUTE =
            I2C_ROUTE_LOCATION(4) | I2C_ROUTE_SCLPEN | I2C_ROUTE_SDAPEN;
        I2C0_CLKDIV = 6;
        I2C0_CMD = I2C_CMD_ABORT;

        // configure the ADC
        ADC0_CTRL = ADC_CTRL_TIMEBASE(23) | ADC_CTRL_PRESC(1) |
                    ADC_CTRL_LPFMODE_RCFILT | ADC_CTRL_WARMUPMODE_KEEPADCWARM;

        // init USB
        uint32_t unique0 = DI_UNIQUE_0;
        uint32_t unique1 = DI_UNIQUE_1;

        serial_string[16] = 0;
        hex_str(unique0, serial_string + 0);
        hex_str(unique1, serial_string + 8);

        usbd_dev = usbd_init(&efm32hg_usb_driver, &usb_dev_descr,
                             &usb_config_descr, usb_strings, 3,
                             usbd_control_buffer, sizeof(usbd_control_buffer));

        usbd_register_set_config_callback(usbd_dev, usb_set_config);

        nvic_set_priority(NVIC_USB_IRQ, 0x10);
        nvic_enable_irq(NVIC_USB_IRQ);

        nvic_enable_irq(NVIC_TIMER1_IRQ);
        nvic_set_priority(NVIC_TIMER1_IRQ, 0x10);

        // Configure the system tick
        STK_RVR = 0xFFFFFF;
        STK_CSR = STK_CSR_CLKSOURCE_AHB | STK_CSR_ENABLE;

        nvic_set_priority(NVIC_GPIO_EVEN_IRQ, 0x20);
        nvic_enable_irq(NVIC_GPIO_EVEN_IRQ);

        OLED_init();
        // OLED is super slow to power on
        // Fails at 1500 ms, suceeds at 1600 ms
        // sometimes fails at 1800 ms cold boot
        delay(160 * TIMER_MS);

        OLED_init();

        Timer t_display;

        while (1) {
                Timer t{};
                while (t.elapsed() < TIMER_MS * 250)
                        ;
                GPIO_IFS = (1 << 2); // force an interrupt

                char tempstr[9];
                hex_str(t_display.elapsed(), tempstr);
                tempstr[8] = 0;
                OLED_text(tempstr, 128);

                hex_str(isr_count, tempstr);
                OLED_text(tempstr, 192);

                int adct = correct_temp(read_adc(8, 0));

                temperature_str(adct, tempstr);
                OLED_text(tempstr, 384 + 42);

                hex_str(encoder.get_angle(), tempstr);
                OLED_text("encoder ", 896, encoder.pushed_raw() ? 0xFF : 0x00);
                OLED_text(tempstr, 48 + 896);

                OLED_update();
        }

        return 0;
}

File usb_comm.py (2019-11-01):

#!/usr/bin/env python3

import usb.core
import usb.util

import sys
import time
from struct import pack, unpack
from datetime import datetime

class USBSpiDev:
    def __init__(self, product):
        self.dev = usb.core.find(idVendor=0x1209, idProduct=0xf00f)
        dev = self.dev
        if self.dev is None:
            raise ValueError('Device not found')
        self.dev.set_configuration()
        self.cfg = self.dev.get_active_configuration()
        self.intf = self.cfg[(0,0)]
        print(self.dev)
        print("Manufacturer =", usb.util.get_string(dev, dev.iManufacturer))
        print("Product = ", usb.util.get_string(dev, dev.iProduct))
        print("Serial = ", usb.util.get_string(dev, dev.iSerialNumber))

    def out_2(self, a, b):
        self.dev.write(1, pack("II", a, b))
    def out_3(self, a, b, c):
        self.dev.write(1, pack("III", a, b, c))
    def bulk_in(self, n):
        return bytes(self.dev.read(0x82, n,100))
    def bulk_in_32(self):
        (rv,) = unpack("i", self.bulk_in(4))
        return rv
    def r(self,a):
        self.out_2(5, (1<<23) | (a<<16))
        return self.bulk_in_32()
    def w(self, a, d):
        self.out_2(4, (a<<16) | (d&0xFFFF))
    def w32(self, a, d):
        self.w(a+1, d&0xFFFF)
        self.w(a, d>>16)
    def devinfo(self):
        self.out_2(0, 0)
        rv = unpack("IIII", self.bulk_in(16))
        print("uc manufactured",
              datetime.utcfromtimestamp(rv[0]).strftime('%Y-%m-%d %H:%M'))
        for i in range(4):
            print('info {} = 0x{:8X}'.format(i, rv[i]))
        return rv

    def adc(self, source, ref):
        self.out_3(3, source, ref)
        return self.bulk_in_32()
    def get_temp(self):
        return self.adc(8,0)/10.0
    def get_vcc(self):
        return 1.25*3.0*self.adc(9,0)/4096.0

if __name__ == "__main__":

    dev = USBSpiDev("Kicad workshop")
    dev.devinfo()
    print("temp", dev.get_temp(), "C")
    print("vcc", dev.get_vcc(), "V")

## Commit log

2019-07-14 add libraries and example of completed PCB
    [kicad-workshop.kicad_pcb, kicad-workshop.sch]
2019-08-16 initial quick and dirty microcontroller code
    [flash.cfg]
2019-08-16 reduce solder paste on USB C
2019-09-26 add note about HTML BOM dependency
2019-11-01 use pid.codes USB ID http://pid.codes/1209/F00F/
2019-11-01 update readme - LED, Kicad version
2019-11-09 change LED to single color The 1x1 mm LED was too difficult for assembly, mostly locating pin 1
    [kicad-workshop.kicad_pcb, kicad-workshop.sch]
2019-11-09 reduce solder paste volume on USB C
2019-12-11 change LED GPIO to push pull for later boards
2021-10-19 update kicad link
